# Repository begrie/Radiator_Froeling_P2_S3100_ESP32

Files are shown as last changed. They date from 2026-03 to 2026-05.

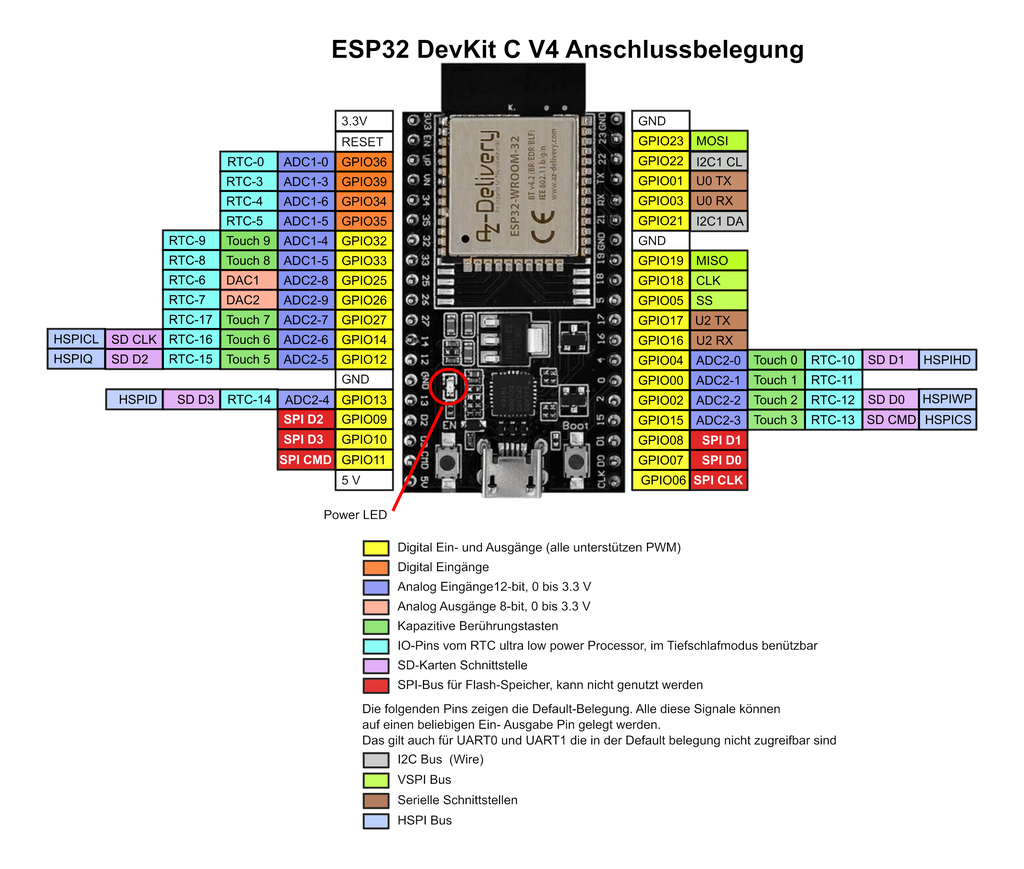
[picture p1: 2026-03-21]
Fotos/Pinout_ESP32DevkitCV4_AZDelivery.png

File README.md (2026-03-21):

# Überwachungstool für Fröling P2 / Lambdatronic S 3100 — ESP32-Adaptation

> **ESP32-Adaptation** von Bernd Griesbach (BeGrie) — basierend auf dem ursprünglichen Raspberry-Pi-Projekt von [Daniel Höpfl (dhoepfl/Radiator)](https://github.com/dhoepfl/Radiator).

## Anpassung für ESP32 (BeGrie, Sept./Okt. 2022)

Im Zuge der Energiekrise 2022 und einem Pelletspreisanstieg von 200 auf 800 Euro je Tonne habe ich mein seit langem geplantes und immer wieder beiseite geschobenes Projekt (Heizung seit 2006 im Betrieb) der Heizungsüberwachung wieder aktiviert um Optimierungspotentiale zu erschließen.

Bei der Recherche nach Lösungen bin ich unter anderem auf dieses Projekt von Daniel Höpfl gestoßen und war von Analyse des P2/S3100-Kommunikationsprotokolls und der professionellen Umsetzung in Sourcecode begeistert. Hiermit huldige ich dem Meister, von dem ich aus seinem Projekt einiges lernen durfte! Vielen Dank dafür!

Als ESP32 Nutzer habe ich mangels RasPi Erfahrungen und fehlender Erläuterungen im Projekt (sorry) doch etwas gebraucht, um den gesamten Ablauf auf dem RasPi mittels C++, Autoconf/Automake, Python und Shellskripten in Kombination mit mysql, rrd, Vu, mailserver etc. zu verstehen. Nun ist alles klar, aber ich brauche so viele Features davon nicht und bleibe doch lieber in den mir bekannten ESP32-Gefilden ...

Die ESP32 Lösung besteht nur noch aus dem C++ Sourcecode, bei dem ich im wesentlichen folgendes geändert bzw. ergänzt habe:

- main.cpp neu für ESP32 mit Platformio (bei mir in VSCode) -> Platform Espressif32 und Arduino framework 3.x

- Serieller Input (in serial.cpp) über Serial2 realisiert (hardwareseitig wie beim RasPi über RS232-Schnittstellenumsetzer → bei mir SparkFun Transceiver Breakout - MAX3232 https://www.sparkfun.com/products/11189)

- Output fast komplett neu (output.h/.cpp, network.h/.cpp, files.h/.cpp) → nun "autark" (ohne externe Skripte o.ä) auf
  - Console/Serial,
  - Flash/LittleFS (wg. geringem Speicherplatz nur zum Testen sinnvoll),
  - SD Card (hardwareseitig jeder 3,3V SD Reader an den ESP32 anschliessbar). Aktuell muss die SD Card entnommen und am PC eingelesen werden.
  - Buzzer (aktiv) und Quit-Button zur akustischen Fehlermeldung im Keller
  - WiFi ...
    _ ... inkl. Konfiguration über console/Serial per USB-Anschluss → beim Booten den Quit-Button drücken
    _ ... zum Versand von MQTT-Nachrichten (Konfiguration wie bei WiFi) \* ... mit Webserver zum Datenabgriff von der SD-Card

- Die Konfiguration bzgl. Filesystem, Output und weiterem Verhalten erfolgt ausschließlich über die #defines in config.h, was bei Änderungen natürlich eine Neucompilierung erfordert (ich weiss: nicht schön - aber der kürzeste Weg). Dies sollte aber durch die Nutzung von Platformio über die hier enthaltene platformio.ini problemlos möglich sein ...

- Schaltplan zur Konfiguration im Sourcecode:
  Schaltplan

- Fotos zur Umsetzung:
  Foto Platine oben
  Foto Platine unten
  Foto Heizung

Falls jemand die ESP32 Anpassung nutzt, bin ich für Rückmeldungen, Verbesserungen, Pull requests etc. offen ...

---

## Hintergrund: Originaltext von Daniel Höpfl ([dhoepfl/Radiator](https://github.com/dhoepfl/Radiator))

_Der folgende Abschnitt stammt aus dem ursprünglichen Raspberry-Pi-Projekt, auf dem diese ESP32-Adaptation basiert. Er enthält die detaillierte Protokollanalyse der Fröling P2 / Lambdatronic S 3100 Schnittstelle._

## Vorgeschichte

Fast alle Geräte in unserem Haushalt haben einen eingebauten Signalgeber, um uns zu informieren, wenn sie etwas von uns brauchen: Die Spülmaschine piept, wenn sie fertig ist, die Mikrowelle hat eine laute Klingel, die Waschmaschine ebenso, wie der Trockner. Das einzige Gerät, das keinen Ton von sich gibt, wenn es eine Störung erkennt, ist die Fröling P2 Pellet-Heizung im Keller. Es ist nicht so, dass die Heizung keine Störungen hätte oder diese nicht erkennt, nein: Wenn zum Beispiel ein zu großes Pellet den Saugschlauch blockiert, dann erkennt die Heizung das und ihre Status-LED blinkt nicht länger grün sondern rot. Dass wir das nicht bemerken, weil die Heizung hinter verschlossener Türe im Heizungskeller steht, daran hat bei Fröling wohl niemand gedacht.

Mein erster Ansatz war, eine kleine Überwachung zu bauen, die die Farbe der LED erkennt und darauf basierend einen Alarm auslöst. Ich bin Softwerker, kein Hardware-Profi. An der Erkennung der Farbe (zu kleinem Preis) bin ich gescheitert. Noch während ich daran gearbeitet habe, bin ich darauf gestoßen, dass die P2 bzw. die darin verbaute Lambdatronic S 3100 eine serielle Schnittstelle hat, über die sie praktisch voll bedienbar ist. Da ich zunächst eine Lösung wollte, für die ich mich nicht direkt mit der Heizung verbinden muss (Gewährleistung, Diskussionen mit dem Service, ...), habe ich diese Möglichkeit zunächst nicht weiter verfolgt.

Nachdem wir in den letzten Wochen mehrmals (Pellets-Lager wird leer) durch kaltes Wasser auf die Farbe der LED hingewiesen wurden, habe ich das Projekt wiederbelebt. Dieses Mal ist mir der Mitarbeiter der Wartungsfirma egal.

## Protokollanalyse

Das Protokoll der S 3100 ist halbwegs gut analysiert. Die beste Quelle ist [dieser Thread bei mikrocontroller.net](http://www.mikrocontroller.net/topic/319990 "Fröling Heizungssteuerung auslesen"). Auch wertvoll ist [dieser Eintrag auf rigert.com](http://rigert.com/wiki-wiki/index.php?title=Fr%C3%B6ling). Die einzige Quelle, die „M3“ erwähnt ist [das hier verlinkte Archiv eines Foren-City-Threads](http://www.labviewforum.de/Thread-Mit-RS232-Daten-lesen-und-schreiben?pid=159201#pid159201).

Die drei Quellen scheinen größtenteils voneinander abzuschreiben (Forencity ist dabei der älteste, gefolgt von mikrocontroller und dann rigert.com), allen gemein ist, dass meiner Ansicht nach keiner der dort Mitschreibenden das Protokoll verstanden hat. Da wird davon gesprochen, dass 32 Mal ein bestimmter Befehl gesendet werden müsste, um die Kommunikation am Laufen zu halten, oder dass man abwechselnd „M1“ und „M2“ abfragen müsste. Ich halte das für Blödsinn.

Nach meinen Analysen sieht das Protokoll wie folgt aus:

### Datenpakete

Das Protokoll basiert auf Datenpaketen mit folgender Struktur:

| Bytes | Beschreibung |
| ----- | --- |
| 2 | Befehl |
| 1 | Länge (n) |
| n | Daten |
| 2 | Prüfsumme |

Dabei gilt:

- Für eine Liste der bekannten Befehle siehe unten. Soweit ich sehen konnte, beginnen Befehle, die von der Heizung gesendet werden, mit „M“, Befehle, die vom Endgerät ausgehen, beginnen mit „R“. (Achtung: Das gilt nicht für Bestätigungen)
- Die Länge zählt nur die Datenbytes, Header und Prüfsumme bleiben unberücksichtigt.
- Die Prüfsumme ist eine einfache, vorzeichenlos berechnete, 16 Bit breite Summe über Befehl, Länge und Daten.

## Ablauf

Hier widerspreche ich den oben verlinkten Quellen: Meiner Meinung nach sieht das Protokoll vor, dass jedes Datenpaket mit einer Bestätigung quittiert wird. Dabei folgt das Bestätigungspaket folgendem Schema:

| Bytes | Beschreibung |
| ----- | --- |
| 2 | Befehl, der quittiert wird |
| 1 | Länge (immer 1) |
| 1 | 0x01 für Bestätigung (ACK), 0x00 für Fehler (NACK) |
| 2 | Prüfsumme |

Der Ablauf im Programm kann also wie folgt aussehen:

1.  Benutze einen Puffer für mindestens 260 Bytes (2 Bytes Befehl, 1 Byte Länge, max. 255 Bytes Daten, 2 Bytes Prüfsumme).
2.  5 Bytes von der seriellen Schnittstelle lesen (2 Byte Befehl, 1 Byte Länge, 2 Bytes Prüfsumme)
3.  Wenn Länge > 0: Entsprechend weitere Bytes lesen.
4.  Die Prüfsumme prüfen.
    - Ist sie ungültig: NACK senden, weiter bei 1.
    - Ist sie gültig: ACK senden, weiter bei 5.
5.  Bestätigungen behandeln:
    - Wurde der entsprechende Befehl gesendet und ist die Länge 1 und ist der Wert 0x01? Dann ist der Befehl quittiert, weiter bei 1.
    - Wurde der entspechende Befehl gesendet und ist die Länge 1 und ist der Wert 0x00? Dann Befehl erneut senden, weiter bei 1.
    - Wurde der entsprechende Befehl nicht gesendet oder ist die Länge nicht 1, dann weiter bei 6.
6.  Befehl behandeln.

## Bekannte Befehle

Hier die Beschreibung der Befehle, so wie ich sie zusammengetragen und verstanden habe. Das unterscheidet sich zum Beispiel bei „M1“ von dem, was man in den Foren findet, dort wird immer von einer festen Reihenfolge ausgegangen. Für eine bestimmte Heizung stimmt das vermutlich auch, solange nichts neues angeschlossen wird.

Alle Texte, die übertragen werden, sind übrigens in „Codepage 850“ kodiert. Ein (Mapping zu Unicode findet sich z.B. bei der Wikipedia)[https://de.wikipedia.org/wiki/Codepage_850].

### Login („Ra“)

| Bytes | Wert | Beschreibung |
| ----- | --- | --- |
| 2 | 0x52 0x61 | Login-Befehl |
| 1 | 0x03 | Länge 3 |
| 1 | 0x00 | unbekannt |
| 2 | 0x.. 0x.. | Benutzer-Kennung (-7: 0xff 0xf9 für Service, 1/0x00 0x01 für Kunde) |
| 2 | 0x.. 0x.. | Prüfsumme |

Die Heizung antwortet darauf mit einem ACK (siehe Ablauf) und sendet daraufhin die Befehlsblöcke MA, MB, MC, MD, ME, MF, MG, MK, ML, MM, MW, MS, MT und MU, jeweils beendet durch entsprechende MZ Befehle. Anschließend beginnt die Heizung regelmäßig M2 zu senden.

### Status („Rb“)

| Bytes | Wert | Beschreibung  |
| ----- | --- | --- |
| 2 | 0x52 0x62 | Status-Befehl |
| 1 | 0x03 | Länge 3 |
| 3 | 0x00 0x00 0x00 | unbekannt |
| 2 | 0x.. 0x.. | Prüfsumme |

Die Heizung antwortet darauf mit einem ACK (siehe Ablauf) und sendet ab sofort regelmäßig die Messwerte (M1).

### Parameter ändern („RI“)

Ändert einen der Werte der Heizung. Die verfügbaren Werte werden in „ME“ beschrieben.

| Bytes | Wert | Beschreibung |
| ----- | --- | --- |
| 2 | 0x52 0x49 | Befehl |
| 1 | 0x04 | Länge |
| 2 | 0x.. 0x.. | Parameter-ID |
| 2 | 0x.. 0x.. | Neuer Wert |
| 2 | 0x.. 0x.. | Prüfsumme |

Die Heizung antwortet darauf mit einem ACK/NACK (siehe Ablauf), anschließend kommt der neue Wert über „MI“.

### Messwerte („M1“)

Auch hier muss ich den Angaben aus den Foren widersprechen: Der Inhalt von M1 ist nicht fest vorgegeben, es hängt davon ab, was wie die Heizung installiert wurde. Welche Werte geliefert werden und wie diese zu interpretieren sind, kann man aus der „MA“- bzw. „MC“ Antworten ableiten, die man beim Login bekommt. Für meine Heizung sind das die folgenden Werte, für andere Heizungen können es andere Werte (oder Reihenfolgen) sein.

| Bytes | Wert | Beschreibung | Faktor | Einheit |
| ----- | --- | --- | :----: | :-----: |
| 2 | 0x4D 0x31 | Status-Befehl | | |
| 1 | 0x.. | Länge | | |
| 2 | 0x.. 0x.. | 1. Displayzeile | | |
| 2 | 0x.. 0x.. | 2. Displayzeile | | |
| 2 | 0x.. 0x.. | Zustand | 1 | -/- |
| 2 | 0x.. 0x.. | Rost | 1 | -/- |
| 2 | 0x.. 0x.. | Kessel-Temperatur | 2 | °C |
| 2 | 0x.. 0x.. | Abgas-Temperatur | 1 | °C |
| 2 | 0x.. 0x.. | Abgas Schwellwert | 1 | °C |
| 2 | 0x.. 0x.. | KesselStellGr | 1 | % |
| 2 | 0x.. 0x.. | Saugzug | 1 | % |
| 2 | 0x.. 0x.. | Zuluft-Gebläse | 1 | % |
| 2 | 0x.. 0x.. | Einschub | 1 | % |
| 2 | 0x.. 0x.. | Rest-O2 |  100 | % |
| 2 | 0x.. 0x.. | O2-Regler |  100 | % |
| 2 | 0x.. 0x.. | Füllstand |  207 | % |
| 2 | 0x.. 0x.. | Feuerraum-Temperatur | 2 | °C |
| 2 | 0x.. 0x.. | Puffer oben | 2 | °C |
| 2 | 0x.. 0x.. | Puffer unten | 2 | °C |
| 2 | 0x.. 0x.. | Puffer Pu | 1 | % |
| 2 | 0x.. 0x.. | Boiler | 2 | °C |
| 2 | 0x.. 0x.. | Außentemperatur | 2 | °C |
| 2 | 0x.. 0x.. | Vorlauf 1 Schwellwert  | 2 | °C |
| 2 | 0x.. 0x.. | Vorlauf 1 | 2 | °C |
| 2 | 0x.. 0x.. | Vorlauf 2 Schwellwert  | 2 | °C |
| 2 | 0x.. 0x.. | Vorlauf 2 | 2 | °C |
| 2 | 0x.. 0x.. | KTY6_H2 | 2 | °C |
| 2 | 0x.. 0x.. | KTY7_H2 | 2 | °C |
| 2 | 0x.. 0x.. | Brennerstarts | 1 | -/- |
| 2 | 0x.. 0x.. | Betriebsstunden | 1 | h |
| 2 | 0x.. 0x.. | Board-Temperatur | 1 | °C |
| 2 | 0x.. 0x.. | Kessel Soll-Temperatur | 2 | °C |
| 2 | 0x.. 0x.. | Prüfsumme | | |

### Zeit („M2“)

| Bytes | Wert | Beschreibung |
| ----- | --- | --- |
| 2 | 0x4D 0x32 | Befehl |
| 1 | 0x07 | Länge |
| 1 | 0x.. | Sekunden |
| 1 | 0x.. | Minuten |
| 1 | 0x.. | Stunden |
| 1 | 0x.. | Tag |
| 1 | 0x.. | Monat |
| 1 | 0x.. | Wochentag (1: Montag, ..., 7: Sonntag) |
| 1 | 0x.. | Jahr |
| 2 | 0x.. 0x.. | Prüfsumme |

Alle Werte sind BCD, d.h. die oberen 4 Bit beschreiben die Zehner-Stelle, die unteren 4 Bit die Einer-Stelle.

### Fehlermeldung („M3“)

Wird gesendet, wenn ein Fehler auftritt. Vermutlich die interessanteste Meldung überhaupt, jedenfalls für meinen Anwendungszweck!

| Bytes | Wert | Beschreibung |
| ----- | --- | --- |
| 2 | 0x4D 0x33 | Befehl |
| 1 | 0x0a | Länge |
| 1 | 0x.. | Fehlertext-ID |
| 1 | 0x.. | Unbekannt |
| 1 | 0x.. | Unbekannt |
| 1 | 0x.. | Sekunden |
| 1 | 0x.. | Minuten |
| 1 | 0x.. | Stunden |
| 1 | 0x.. | Tag |
| 1 | 0x.. | Monat |
| 1 | 0x.. | Wochentag (1: Montag, ..., 7: Sonntag) |
| 1 | 0x.. | Jahr |
| 2 | 0x.. 0x.. | Prüfsumme |

Der Inhalt entspricht dem von „MU“, die Fehlertext-ID ist analog denen in „MT“.

### Bezeichnung der Parameter in „M1“ („MA“)

Diese Nachrichten müssen ausgewertet werden, um den Inhalt von „M1“ auswerten zu können. Die Werte in „M1“ sind jeweils 2 Byte lang und werden in genau der Reihenfolge gesendet, in der auch die „MA“ Nachrichten gesendet wurden.

| Bytes | Wert | Beschreibung |
| ----- | --- | --- |
| 2 | 0x4D 0x41 | Befehl |
| 1 | 0x.. | Länge |
| 1 | 0x.. | 'S': String, 'I': Messwerte |
| 2 | 0x.. 0x.. | 'S': Typ in „MB“, 'I': Index in „MC“ |
| 2 | 0x.. 0x.. | Unbekannt |
| n | ... | Parameterbezeichnung |
| 2 | 0x.. 0x.. | Prüfsumme |

### Displaytexte („MB“)

Enthält die Texte, die in „MA“ referenziert werden. Bisher bekannt sind die beiden Typen 0 und 1, welche in der ersten bzw. zweiten Displayzeile angezeigt werden.

| Bytes | Wert | Beschreibung |
| ----- | --- | --- |
| 2 | 0x4D 0x42 | Befehl |
| 1 | 0x.. | Länge |
| 2 | 0x.. 0x.. | Typ (0: obere Displayzeile, 1: untere Displayzeile) |
| 2 | 0x.. 0x.. | Index der Nachricht |
| n | Text | Nachrichtentext |
| 2 | 0x.. 0x.. | Prüfsumme |

### Datenformat der Werte in „M1“ („MC“)

Beschreibt, wie die Daten in „M1“ formatiert werden müssen. Da es bei mir deutlich mehr „MC“-Datensätze, als für „MA“ gibt, gehe ich davon aus, dass die übrigen Einträge anderweitig referenziert werden. Wo habe ich noch nicht herausgefunden.

| Bytes | Wert | Beschreibung |
| ----- | --- | --- |
| 2 | 0x4D 0x43 | Befehl |
| 1 | 0x08 | Länge |
| 2 | 0x.. 0x.. | Index |
| 1 | 0x.. | Einheit (Codepage 850 beachten!) |
| 1 | 0x.. | Anzahl der Nachkommastellen |
| 2 | 0x.. 0x.. | Anzuwendender Teiler |
| 2 | 0x.. 0x.. | Unbekannt (Häufig gleich Teiler, aber nicht immer) |
| 2 | 0x.. 0x.. | Prüfsumme |

### Einstellungsmenü („MD“)

Aus den Foren übernommen, Zweck unbekannt.

| Bytes | Wert | Beschreibung |
| ----- | --- | --- |
| 2 | 0x4D 0x44 | Befehl |
| 1 | 0x.. | Länge |
| 1 | 0x.. | Unbekannt |
| 2 | 0x.. 0x.. | Unbekannt |
| 2 | 0x.. 0x.. | Unbekannt |
| 2 | 0x.. 0x.. | Unbekannt |
| n | | Text |
| 2 | 0x.. 0x.. | Prüfsumme |

### Parameterbeschreibung („ME“)

Aus den Foren übernommen, Zweck unbekannt. Hängt vermutlich mit „MD“ zusammen.

| Bytes | Wert | Beschreibung |
| ----- | --- | --- |
| 2 | 0x4D 0x45 | Befehl |
| 1 | 0x.. | Länge |
| 2 | 0x.. 0x.. | Parameter-ID |
| 1 | 0x.. | Einheit |
| 1 | 0x.. | Nachkommastellen |
| 2 | 0x.. 0x.. | Faktor |
| 2 | 0x.. 0x.. | Minimalwert |
| 2 | 0x.. 0x.. | Maximalwert |
| 2 | 0x.. 0x.. | Standardwert |
| 5 | ... | Unbekannt |
| 2 | 0x.. 0x.. | Prüfsumme |

### Texte Betriebsmodus („MF“)

Enthält je einen Eintrag für die Betriebsmodi („Sommerbetrieb“, „Winterbetrieb“, …). Wo die Einträge referenziert werden ist nicht mir noch nicht klar.

| Bytes | Wert | Beschreibung |
| ----- | --- | --- |
| 2 | 0x4D 0x46 | Befehl |
| 1 | 0x.. | Länge |
| 2 | 0x.. 0x.. | Text-ID |
| n | ... | Text |
| 2 | 0x.. 0x.. | Prüfsumme |

### Wochenprogramm Heizkreise („MG“)

Noch nicht weiter analysiert.

| Bytes | Wert | Beschreibung |
| ----- | --- | --- |
| 2 | 0x4D 0x47 | Befehl |
| 1 | 0x12 | Länge |
| 2 | 0x.. 0x.. | Heizkreis-Nummer |
| 1 | 0x.. | Unbekannt |
| 7 | ... | Programmnummer für jeden Tag (Sonntag - Samstag), siehe MK |
| 1 | 0x.. | Unbekannt |
| 7 | ... | Programmnummer für jeden Tag (Sonntag - Samstag), siehe MK |
| 2 | 0x.. 0x.. | Prüfsumme |

### Parameteränderung („MI“)

Wird gesendet, wenn einer der Heizungsparameter geändert wurde (z.B. durch Befehl „RI“).

| Bytes | Wert | Beschreibung |
| ----- | --- | --- |
| 2 | 0x4D 0x49 | Befehl |
| 1 | 0x04 | Länge |
| 2 | 0x.. 0x.. | Parameter-ID |
| 2 | 0x.. 0x.. | Neuer Wert |
| 2 | 0x.. 0x.. | Prüfsumme |

### Tagesprogramm („MK“)

Noch nicht weiter analysiert.

| Bytes | Wert | Beschreibung |
| ----- | --- | --- |
| 2 | 0x4D 0x4B | Befehl |
| 1 | 0x06 | Länge |
| 2 | 0x.. 0x.. | Programmnummer |
| 2 | 0x.. 0x.. | Unbekannt |
| 2 | 0x.. 0x.. | Unbekannt |
| 2 | 0x.. 0x.. | Prüfsumme |

### Produktnamen („ML“)

Enthält diverse Namen von Heizungen. Wo diese Texte referenziert werden ist mir noch nicht klar.

| Bytes | Wert | Beschreibung |
| ----- | --- | --- |
| 2 | 0x4D 0x4C | Befehl |
| 1 | 0x.. | Länge |
| 10 | ... | Unbekannt |
| n | ... | Name |
| 2 | 0x.. 0x.. | Prüfsumme |

### Features („MM“)

Enthält diverse Meldungen, welche Optionen eingebaut sind. Wo diese Texte referenziert werden ist mir noch nicht klar.

| Bytes | Wert | Beschreibung |
| ----- | --- | --- |
| 2 | 0x4D 0x4C | Befehl |
| 1 | 0x.. | Länge |
| 4 | ... | Unbekannt |
| n | ... | Meldung |
| 2 | 0x.. 0x.. | Prüfsumme |

### Weitere texte („MW“)

Wo diese Texte referenziert werden ist mir noch nicht klar.

| Bytes | Wert | Beschreibung |
| ----- | --- | --- |
| 2 | 0x4D 0x4C | Befehl |
| 1 | 0x.. | Länge |
| 2 | ... | Unbekannt |
| n | ... | Text |
| 2 | 0x.. 0x.. | Prüfsumme |

### Fehlerprotokoll-Texte („MT“)

Enthält Beschreibungen für mögliche Fehler im Fehlerprotokoll „MU“.

| Bytes | Wert | Beschreibung |
| ----- | --- | --- |
| 2 | 0x4D 0x54 | Befehl |
| 1 | 0x.. | Länge |
| 1 | 0x.. | Text-ID |
| n | ... | Text |
| 2 | 0x.. 0x.. | Prüfsumme |

### Fehlerprotokoll („MU“)

| Bytes | Wert | Beschreibung  |
| ----- | --- | --- |
| 2 | 0x4D 0x55 | Befehl |
| 1 | 0x.. | Länge |
| 1 | 0x.. | Fehlertext-ID |
| 1 | 0x.. | Unbekannt |
| 1 | 0x.. | Unbekannt |
| 1 | 0x.. | Sekunden |
| 1 | 0x.. | Minuten |
| 1 | 0x.. | Stunden |
| 1 | 0x.. | Tag |
| 1 | 0x.. | Monat |
| 1 | 0x.. | Unbekannt |
| 1 | 0x.. | Jahr |
| 2 | 0x.. 0x.. | Prüfsumme |

### Fehlerprotokoll („MV“)

Dass es „MV“ gibt weiß ich, weil ich ein entsprechendes „MZ“ gesehen habe. Allerdings habe ich noch kein „MV“ gesehen.

### Blockende („MZ“)

Beendet die Übertragung eines der obigen Daten-Blöcke.

| Bytes | Wert | Beschreibung |
| ----- | --- | --- |
| 2 | 0x4D 0x55 | Befehl |
| 1 | 0x01 | Länge |
| 1 | 0x.. | Beendeter Block |
| 2 | 0x.. 0x.. | Prüfsumme |

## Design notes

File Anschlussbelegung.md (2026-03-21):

# Froeling P2 ESP32

## Anschlussbelegung (GPIO)

Stand: aus src/config.h und aktueller Code-Nutzung

## Seriell

- USB-Konsole (Setup/Logs): UART0 ueber Board-USB, Monitor 115200 Baud
- Hinweis: RS232-TTL Wandler noetig (z. B. MAX3232):
  - Heizung P2/S3100 RX: GPIO16 (ESP-Eingang), Serial2 mit 9600 8N1
  - Heizung P2/S3100 TX: GPIO17 (ESP-Ausgang), Serial2 mit 9600 8N1

## Speicher

- SD Card CS: GPIO5 (Ausgang)
- SD SPI SCK: GPIO18
- SD SPI MISO: GPIO19
- SD SPI MOSI: GPIO23
- SD SPI Speed: 4 MHz
- Hinweis: entspricht der ueblichen VSPI-Belegung beim ESP32 DevKit

## Bedienung / Signale

- Buzzer (aktiv): GPIO27, digital HIGH/LOW
- Quit-/Setup-Button: GPIO13, INPUT_PULLUP, aktiv LOW
- Button-Funktion beim Boot: WLAN/MQTT-Setup starten
- Button-Funktion im Betrieb: Buzzer quittieren

## Externe Sensoren / Aktoren

- DHT11 Temp/Feuchte: GPIO21
  Aktiv nur wenn USE_EXTERNAL_SENSORS=true und WITH_DHT_SENSOR=true

- Ventilator-Relais: GPIO22
  Aktiv nur wenn USE_EXTERNAL_SENSORS=true und WITH_VENTILATOR=true

- Servo Luftklappe: GPIO25
  Aktiv nur wenn USE_EXTERNAL_SENSORS=true und WITH_AIR_INPUT_FLAP=true

- Leckwasser-Sensor: GPIO39 (Eingang)
  Aktiv wenn USE_EXTERNAL_SENSORS=true
  Hinweis: GPIO39 ohne internen Pullup, Auswertung per Interrupt (CHANGE)

- AC-Stromsensor: GPIO33 (Analog-Eingang)
  Aktiv wenn USE_EXTERNAL_SENSORS=true

## Aktueller Feature-Status

- USE_WIFI=true
- START_WEBSERVER=false
- OUTPUT_TO_MQTT=true
- OUTPUT_TO_FILE=true
- USE_EXTERNAL_SENSORS=true
- WITH_DHT_SENSOR=false
- WITH_VENTILATOR=false
- WITH_AIR_INPUT_FLAP=false

## Kurzcheck vor Verdrahtung

1. Heizungsschnittstelle auf GPIO16/17 und 9600 8N1 pruefen.
2. Buzzer auf GPIO27, Button auf GPIO13 gegen GND (aktiv LOW).
3. SD-CS auf GPIO5 pruefen.
4. SD-SPI-Leitungen auf GPIO18/19/23 pruefen (SCK/MISO/MOSI).
5. Externe Sensorik nur verdrahten, wenn der jeweilige Feature-Schalter aktiv ist.

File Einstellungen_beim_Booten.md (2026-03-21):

# Froeling P2 ESP32

## Systemeinstellungen beim Booten ändern

### Voraussetzungen vor dem Boot

- Serielle-Konsole oeffnen (PlatformIO Monitor)
- Monitor-Parameter: 115200 Baud, Echo EIN
- Zeilenende fuer Eingaben: CR oder CRLF

---

### Boot ohne gedrueckten Button (Normalfall)

- ESP nutzt gespeicherte WLAN-Daten aus NVS (persistent)
- WLAN-Verbindung startet im Hintergrund
- MQTT nutzt gespeicherte Broker/User/Pass-Daten
- Kein Konsolen-Dialog

Hinweis:

- Wenn keine gueltigen WLAN-Daten gespeichert sind, kann WLAN-Start fehlschlagen.

---

### Boot MIT gedruecktem gelben Quit-Button (Konfig-Modus)

Button beim Einschalten gedrueckt halten.

Ablauf in der Konsole:

1. WLAN-Scan wird gestartet, gefundene SSIDs werden nummeriert angezeigt.
2. Auswahl eingeben:
   - Zahl 1..N: dieses WLAN verwenden
   - 0: WLAN komplett AUS (gespeicherte AP-Daten loeschen)
   - -1: WLAN unveraendert lassen, nur MQTT-Einstellungen aendern
3. Bei Auswahl 1..N: WLAN-Passwort eingeben.
4. Danach MQTT-Dialog:
   - Broker: ENTER = behalten, 0 = loeschen/deaktivieren, sonst neuer Wert
   - User: ENTER = behalten, 0 = loeschen, sonst neuer Wert
   - Pass: ENTER = behalten, 0 = loeschen, sonst neuer Wert
5. Werte werden persistent im NVS gespeichert.

---

### Schnelle Bedienlogik am Geraet

- Nur normal starten: Button NICHT druecken
- WLAN/MQTT neu einstellen: Button beim Boot druecken
- MQTT abschalten: Im MQTT-Broker-Feld "0" eingeben
- WLAN abschalten: Bei Netzwerkauswahl "0" eingeben

---

### Merksatz

Button beim Boot = Setup-Menue.
Kein Button = gespeicherte Konfiguration verwenden.

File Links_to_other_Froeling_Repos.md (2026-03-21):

Links zu anderen Repositories zu Froeling-Pelletsheizungen

Deamon which fetch sensor data of the 'Lambdatronic s3200' and store to a MySQL database:
https://github.com/horchi/linux-p4d

Fröling P3100 Wifi ESP8266 Wifi Communication
https://github.com/mkliche/froeling-com

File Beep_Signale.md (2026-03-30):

# Froeling P2 ESP32

## Beep-Signale

## Prioritaetsreihenfolge (hoechste zuerst)

| Prio | Signal | Bedeutung |
| ---- | --- | --- |
| 6 | Dauerton | Leckwasser |
| 5 | Stotter-Alarm | Grenzwert ueberschritten |
| 4 | Intervall-Piepen | Heizungs-Fehlermeldung |
| 3 | Morse-S (···) | Heizung nicht verbunden |
| 2 | Rattern (zyklisch) | SD/Dateisystem-Problem (ESP) |
| 1 | 2 langsame Beeps | WiFi unterbrochen (ESP) |

---

## Quit-Taste (gelbe Taste an ESP-Box)

- Stoppt den aktiven Buzzer sofort.
- Bei **Heizungsalarmen (Prio 3-6):** Buzzer pausiert fuer **1 Minute**. Danach kommt der Alarm erneut, solange die Ursache noch besteht.
- Alarme der Heizungssteuerung (Prio 4) muessen zudem **ZUERST an der Heizung selbst** quittiert werden.
- WLAN-Ausfall hat einen eigenen zyklischen Buzzer (Prio 1) (Quit-Taste ohne Wirkung)

---

> **Unterscheidung:** Die Signale sind in zwei Kategorien eingeteilt:
>
> - **HEIZUNG KRITISCH** (Prioritaet 3-6): Direkte Heizungsanlage betroffen -> sofort handeln
> - **ESP-UEBERWACHUNG** (Prioritaet 1-2): Ueberwachungssystem selbst meldet ein Problem

---

## HEIZUNG KRITISCH

### 6) Dauerton (ohne Pause) - PRIO 6

**Bedeutung:** LECKWASSER erkannt
**Aktion:** Sofort auf Wasserleck pruefen, Bereich sichern, Ursache beheben.

---

### 5) Stotter-Alarm in Bloecken - PRIO 5

**Muster:** 4x kurz (120 ms EIN / 120 ms AUS), dann 1 s Pause, Wiederholung
**Bedeutung:** Grenzwert ueberschritten (z. B. Kesseltemperatur > 90 C)
**Aktion:** Anlage und Messwerte sofort kontrollieren.

---

### 4) Langsames Intervall-Piepen - PRIO 4

**Muster:** ca. 0,7 s EIN / 0,7 s AUS
**Bedeutung:** Heizungs-Fehlermeldung (Error-Alarm der Heizungssteuerung)
**Aktionen:**

1. Fehlertext auf Heizungsdisplay pruefen
2. Ursache beheben und Stoerung **an der Heizungssteuerung** quittieren (Enter-Taste)
3. Danach Buzzer an der ESP-Box mit der **gelben Quit-Taste** stoppen

---

### 3) Morse-S (3 kurze Beeps, Pause) - PRIO 3

**Muster:** · · · (3x 150 ms), dann 4 s Pause, Wiederholung
**Bedeutung:** Heizung sendet seit ca. 10 Minuten keine Daten mehr
**Aktion:** Serielle Verbindung Heizung <-> ESP-Box pruefen (Kabel, Stecker), Heizung manuell auf Fehler kontrollieren.

---

## ESP-UEBERWACHUNG

### 2) Rattern (3 Sekunden, alle 5 Minuten) - PRIO 2

**Muster:** sehr schnelle Pulse (~50 ms), klingt wie Rattern, ca. 3 Sekunden lang, dann 5 Minuten Pause, dann Wiederholung
**Bedeutung:** Dateisystem-/SD-Karten-Problem (ESP-Ueberwachung betroffen, nicht Heizung selbst)
**Aktion:** SD-Karte und Dateisystem pruefen; bei Wiederholung ESP-Geraet neu starten durch Reset-Button.

---

### 1) 2 langsame Beeps (alle 60 Sekunden) - PRIO 1

**Muster:** 2 x 600 ms EIN + 300 ms Pause, dann 60 Sekunden Pause, Wiederholung
**Bedeutung:** WiFi-Verbindung unterbrochen (ESP laeuft weiter, kein MQTT moeglich)
**Aktion:** Router/WLAN pruefen. Die Heizungsueberwachung laeuft lokal weiter und protokolliert auf SD-Karte.

---

## Statusinfo (kein Alarm)

### 5 schnelle Beeps (kurz)

**Bedeutung:** WLAN-Verbindung hergestellt
**Aktion:** Keine
_(Hinweis: Die Beeps entfallen, wenn gleichzeitig ein Heizungsalarm aktiv ist.)_

### 3 mittlere Beeps (500 ms, einmalig)

**Bedeutung:** ESP32 wird neu gestartet (Exception/Systemfehler)
**Aktion:** MQTT-Syslog pruefen. Wenn Neustarts sich wiederholen -> Geraet physisch inspizieren.

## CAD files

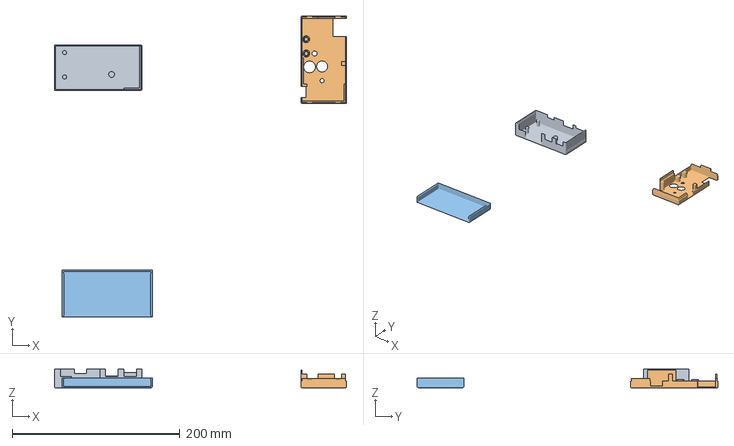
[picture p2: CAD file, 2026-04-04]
FroelingESP32Housing.3mf
348.5 x 359.0 x 22.2 mm
Unterteil
Zusammenbau x 2

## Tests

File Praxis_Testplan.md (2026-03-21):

# Froeling P2 ESP32

## Praxis-Testplan (Kurzcheck vor Ort)

1. **WLAN-Ausfall testen (Prio 1):** WLAN am Router kurz deaktivieren oder ESP aus dem WLAN nehmen -> nach kurzer Zeit muss das Prio-1-Muster zyklisch kommen; nach Wiederverbindung muessen die Alarme verschwinden.
2. **Dateisystem-Hinweis pruefen (Prio 2):** Nur kontrolliert im Servicefall ausloesen (z. B. mit bekannter Testprozedur) -> Rattern muss zyklisch wiederkehren.
3. **Heizung still pruefen (Prio 3):** Serielle Verbindung testweise trennen (Servicefenster) -> nach Timeout muss Morse-S aktiv werden; nach Wiederverbindung wieder aus.
4. **Heizungsfehler pruefen (Prio 4):** Bei realer Heizungsstoerung oder Service-Simulation pruefen -> Intervall-Piepen aktiv; erst an Heizung quittieren, dann gelbe Quit-Taste an ESP testen.
5. **Grenzwertalarm pruefen (Prio 5):** Mit sicherem Testwert/Simulation ueber Schwellwert gehen -> Stotter-Alarm muss sofort aktiv werden und bei Normalwert wieder enden.
6. **Leckwasser pruefen (Prio 6):** Leckwassersensor gemaess Wartungsanleitung ausloesen -> Dauerton muss Prioritaet haben und andere Signale ueberlagern.
7. **Quit-Taste pruefen:** Bei aktivem Prio-3 bis Prio-6 Alarm gelbe Taste druecken -> sofort stumm, danach erneutes Signal nach ca. 1 Minute, falls Ursache weiter aktiv ist.
8. **Restart-Signal pruefen:** Kontrollierten Neustart ausloesen -> einmalig 3 mittlere Beeps; bei wiederholten Neustarts Syslog/MQTT und Stromversorgung pruefen.

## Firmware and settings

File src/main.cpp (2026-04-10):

/******************************************************************************
 * Name:		main.cpp
 * @brief   Überwachungstool für Fröling P2 / Lambdatronic S 3100
 *          -> hier: für ESP32
 *          -> Output auf console, flash-filesystem oder SD-card oder/und MQTT
 *          -> rudimentärer Zugriff per WiFi Async Server
 *          -> IDE: platformio
 * Created:	01.09.2022 (ESP32-adaption)
 * Author:	Original (for Raspberry Pi): Daniel Höpfl
 *          -> https://github.com/dhoepfl/Radiator
 *          Adaption to ESP32: Bernd Griesbach
 *          -> https://github.com/begrie/Radiator_Froeling_S3100_Hoepfl/tree/ESP32
 ******************************************************************************/

/***********************
 *      INCLUDES
 ***********************/
#include "config.h"
#include "debug.h"
#include "device.h"
#include "surveillance.h"
#include "output.h"
#include "files.h"
#include "externalsensors.h"
#include "alarm.h"

/***********************
 *      DEFINES
 ***********************/
// see config.h

/***********************
 *      MACROS
 ***********************/
// see config.h

/***********************
 * FORWARD DECLARATIONS
 ***********************/

/***********************
 * GLOBAL DEFINITIONS
 ***********************/
radiator::NetworkHandler netHandler;
radiator::OutputHandler *ptrOutHandler;

/*********************************************************************
 * @brief 	Setup to start everything
 * @param 	void
 * @return 	void
 *********************************************************************/
void setup()
{
    // int *p = nullptr;
    // *p = 42; // absichtlicher Crash

    Serial.begin(115200);
    delay(1000); // give serial monitor time to connect
    Serial.println("Start setup...");

    bool outputToConsole = OUTPUT_TO_CONSOLE;
    bool outputToMQTT = OUTPUT_TO_MQTT && USE_WIFI; // is turned off without WiFi

    debug_level = D_DEBUG_LEVEL; // var debug_level is globally defined in debug.cpp

    // initialisation of the filesystem at first to minimize heap fragmentation
    std::string pathnameToDataDirectory =
        radiator::FilesystemHandler::initFilesystem(DATA_DIRECTORY); // DATA_DIRECTORY is completed with mountpoint of the filesystem
                                                                     // (/sd/dataDirectory or /littlefs/..., /spiffs/...)

    if (pathnameToDataDirectory.empty())
    {
        std::cout << getMillisAndTime() << "ERROR MOUNTING FILESYSTEM !!! -> Instead: data output to console (std::cout)" << std::endl;
        outputToConsole = true;
    }
    else // filesystem successfull mounted
    {
        // FS_Filehelper::listDir("/", 255, false, FILESYSTEM_TO_USE);

#if REDIRECT_STD_ERR_TO_SYSLOG_FILE
        if (!pathnameToDataDirectory.empty())
            radiator::FilesystemHandler::initRedirectStdErrToSyslogFile();
#endif
    }

    if (!OUTPUT_TO_FILE)
        pathnameToDataDirectory = ""; // empty pathname indicates "no file output" for constuctor of OutputHandler

    if (USE_WIFI)
        outputToMQTT = netHandler.init(outputToMQTT, START_WEBSERVER); // on init-failure -> turn off MQTT

    radiator::AlarmManager::init(); // must be called before any alarm can be raised

#if USE_EXTERNAL_SENSORS
    radiator::ExternalSensors::initExternalSensors();
#endif

    ptrOutHandler = new radiator::OutputHandler(pathnameToDataDirectory, // with empty pathnameToDataDirectory -> no output to file
                                                outputToConsole,
                                                outputToMQTT);

    // ptrOutHandler->setSystemTimeFromRadiatorData(2024, 9, 8, 7, 55, 44);

    RADIATOR_LOG_INFO("\n" << getMillisAndTime()
                           << "***************************************** END STARTUP OF ESP32 *****************************************" << std::endl;)
}

/*********************************************************************
 * @brief 	Loop function
 * @param 	void
 * @return 	void
 *********************************************************************/
void loop()
{
    std::string message;
    message.reserve(800); // an attempt to avoid heap fragmentation
    const char *loopStage = "init";

    // Track how long the boiler has been unreachable.
    // BOILER_SILENT_TIMEOUT_S is defined in config.h.
    static ulong boilerLostSinceMs = 0;
    static bool boilerWasConnected = false;

    try
    {
        loopStage = "build-start-message";
        message = getMillisAndTime() + "##### Start connecting to Froeling P2/S3100 ##### \n";
        loopStage = "publish-start-message";
        netHandler.publishToMQTT(message, MQTT_SUBTOPIC_SYSLOG);
        RADIATOR_LOG_WARN(message << std::endl;)
        if (REDIRECT_STD_ERR_TO_SYSLOG_FILE) // for better user info also to console
            std::cout << message;

        // Start BOILER_SILENT watchdog: if surveillance.main_loop() returns without
        // ever having received data, we count waiting time.
        if (!boilerWasConnected && boilerLostSinceMs == 0)
            boilerLostSinceMs = millis();

        loopStage = "surveillance-main-loop";
        radiator::Surveillance surveillance(S_SERIAL_TO_RADIATOR, T_TIMEOUT_BETWEEN_TRANSFERS_MS, *ptrOutHandler);
        surveillance.main_loop();

        // Only treat boiler as connected if at least one valid packet was received.
        if (surveillance.hadValidPacket())
        {
            loopStage = "connected-message";
            radiator::AlarmManager::clear(radiator::AlarmManager::Level::BOILER_SILENT);

            const std::string connectedMsg = getMillisAndTime() + " ##### CONNECTED to Froeling P2/S3100 #####";
            netHandler.publishToMQTT(connectedMsg, MQTT_SUBTOPIC_SYSLOG);
            RADIATOR_LOG_WARN(connectedMsg << std::endl;)
            if (REDIRECT_STD_ERR_TO_SYSLOG_FILE)
                std::cout << connectedMsg << std::endl;

            boilerWasConnected = true;
            boilerLostSinceMs = 0;
        }
        // Connection dropped after main_loop returned. Re-arm BOILER_SILENT timing
        // so later disconnects are also detected after previous successful sessions.
        else if (boilerWasConnected)
        {
            boilerWasConnected = false;
            boilerLostSinceMs = millis();
        }
        else if (boilerLostSinceMs == 0)
        {
            boilerLostSinceMs = millis();
        }

        loopStage = "build-retry-message";
        message = getMillisAndTime() + "##### Cannot establish connection to Froeling P2/S3100 -> retry in 10s ##### \n";
        loopStage = "publish-retry-message";
        netHandler.publishToMQTT(message, MQTT_SUBTOPIC_SYSLOG);
        RADIATOR_LOG_WARN(message << std::endl;)
        if (REDIRECT_STD_ERR_TO_SYSLOG_FILE) // for better user info also to console
            std::cout << message;

        // Check if boiler has been silent long enough to raise BOILER_SILENT alarm.
        if (boilerLostSinceMs > 0 &&
            (millis() - boilerLostSinceMs) >= (BOILER_SILENT_TIMEOUT_S * 1000UL))
        {
            radiator::AlarmManager::raise(radiator::AlarmManager::Level::BOILER_SILENT,
                                          "Heizung sendet keine Daten - bitte pruefen");
        }

        loopStage = "delay-before-next-loop";
        delay(10000);
    }
    catch (const std::bad_alloc &)
    {
        // Keep this path allocation-free as far as possible.
        Serial.print("FATAL: std::bad_alloc in loop stage '");
        Serial.print(loopStage);
        Serial.println("' -> restarting ESP32 in 10s");

        pinMode(BUZZER_PIN, OUTPUT);
        for (int i = 0; i < radiator::alarmcfg::RESTART_STATUS_BEEP_COUNT; i++)
        {
            digitalWrite(BUZZER_PIN, HIGH);
            delay(radiator::alarmcfg::RESTART_STATUS_ON_MS);
            digitalWrite(BUZZER_PIN, LOW);
            delay(radiator::alarmcfg::RESTART_STATUS_OFF_MS);
        }

        delay(10000);
        esp_restart();
    }
    catch (const char *error)
    {
        const std::string errorText = (error ? error : "<null>");
        message = getMillisAndTime() +
                  " ms: !!!!!!!!!!!!!!!!!!!!!!!!!!!!!!!!!!!!!!!!!!!!!!!!!!!!!!!!!!!!!!!!!!!\n"
                  "!!!!! error= " +
                  errorText +
                  "!!!!! Failed to open serial device or filesystem -> restarting ESP32 in 10s !!!!!\n"
                  "!!!!!!!!!!!!!!!!!!!!!!!!!!!!!!!!!!!!!!!!!!!!!!!!!!!!!!!!!!!!!!!!!!!!!!!!!!!!!!!!!";
        netHandler.publishToMQTT(message, MQTT_SUBTOPIC_SYSLOG);
        LOG_fatal << message << std::endl;
        Serial.println(message.c_str());

        // 3 langsame Beeps = ESP-Neustart (direkt auf GPIO; vor Restart sicher nutzbar)
        pinMode(BUZZER_PIN, OUTPUT);
        for (int i = 0; i < radiator::alarmcfg::RESTART_STATUS_BEEP_COUNT; i++)
        {
            digitalWrite(BUZZER_PIN, HIGH);
            delay(radiator::alarmcfg::RESTART_STATUS_ON_MS);
            digitalWrite(BUZZER_PIN, LOW);
            delay(radiator::alarmcfg::RESTART_STATUS_OFF_MS);
        }

        delay(10000);
        esp_restart();
    }
    catch (const std::exception &e)
    {
        message = getMillisAndTime() + " ms: EXCEPTION in loop(): " + e.what() +
                  " -> restarting ESP32 in 10s";
        netHandler.publishToMQTT(message, MQTT_SUBTOPIC_SYSLOG);
        LOG_fatal << message << std::endl;
        Serial.println(message.c_str());

        // 3 langsame Beeps = ESP-Neustart
        pinMode(BUZZER_PIN, OUTPUT);
        for (int i = 0; i < radiator::alarmcfg::RESTART_STATUS_BEEP_COUNT; i++)
        {
            digitalWrite(BUZZER_PIN, HIGH);
            delay(radiator::alarmcfg::RESTART_STATUS_ON_MS);
            digitalWrite(BUZZER_PIN, LOW);
            delay(radiator::alarmcfg::RESTART_STATUS_OFF_MS);
        }

        delay(10000);
        esp_restart();
    }
    catch (...)
    {
        message = getMillisAndTime() + " ms: UNKNOWN EXCEPTION in loop() -> restarting ESP32 in 10s";
        netHandler.publishToMQTT(message, MQTT_SUBTOPIC_SYSLOG);
        LOG_fatal << message << std::endl;
        Serial.println(message.c_str());

        // 3 langsame Beeps = ESP-Neustart
        pinMode(BUZZER_PIN, OUTPUT);
        for (int i = 0; i < radiator::alarmcfg::RESTART_STATUS_BEEP_COUNT; i++)
        {
            digitalWrite(BUZZER_PIN, HIGH);
            delay(radiator::alarmcfg::RESTART_STATUS_ON_MS);
            digitalWrite(BUZZER_PIN, LOW);
            delay(radiator::alarmcfg::RESTART_STATUS_OFF_MS);
        }

        delay(10000);
        esp_restart();
    }
}

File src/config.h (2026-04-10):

/******************************************************************************
 * Name:		config.h
 * @brief   Konfiguration für Überwachungstool für Fröling P2 / Lambdatronic S 3100
 *          -> hier: für ESP32
 *          -> Output auf console, flash-filesystem oder SD-card oder/und MQTT
 *          -> rudimentärer Zugriff per WiFi Async Server
 *          -> IDE: platformio
 * Created:	01.09.2022 (ESP32-adaption)
 * Author:	Original (for Raspberry Pi): Daniel Höpfl
 *          -> https://github.com/dhoepfl/Radiator
 *          Adaption to ESP32: Bernd Griesbach
 *          -> https://github.com/begrie/Radiator_Froeling_P2_S3100_ESP32
 ******************************************************************************/
#ifndef __DH_CONFIG_H__
#define __DH_CONFIG_H__

/*********************
 *      INCLUDES
 *********************/
#include <Arduino.h>
#include <SD.h>
// #include <LittleFS.h>
// #include <SPIFFS.h>
//  #include <chrono>

namespace radiator
{

/*********************
 *      DEFINES
 *********************/
#define D_DEBUG_LEVEL 2 // 0 - No logging
                        // 1 - Errors
                        // 2 - Warnings
                        // 3 - Infos
                        // 4 - Debug
                        // 5 - Trace

#define REDIRECT_STD_ERR_TO_SYSLOG_FILE false    // debug output to file INSTEAD to console/Serial
                                                 // -> do it only with D_DEBUG_LEVEL 0, 1 or 2
#define SYSLOG_DIR "/syslog"                     // directory for syslog files
#define SYSLOG_PATHNAME SYSLOG_DIR "/syslog.log" // name with path (only one directory level is created automatic)
                                                 // -> watch the needed filespace: makes only sense at long term operation
                                                 //    with D_DEBUG_LEVEL 1 - Errors (or 2 -Warnings)
#define WRITE_TO_SYSLOGFILE_INTERVAL_SEC 60      // controls how often the streambuffer of the syslogfile
                                                 // is written to file and how many data can get lost ... (e.g. 60  -> 60 sec are a good value)
#define MAX_SYSLOG_FILE_SIZE_BYTES (100 * 1024)  // there may be problems with serving too big files (>30 kB?) from AsyncWebserver
#define MAX_OLD_SYSLOG_FILES 15

#define S_SERIAL_TO_RADIATOR "Serial2"      // Serial device for connection to radiator device P2/S3100
#define SERIAL_TO_RADIATOR_RX_PIN 16        // ESP32-standard: 16
#define SERIAL_TO_RADIATOR_TX_PIN 17        // ESP32-standard: 17
#define SERIAL_TO_RADIATOR_BAUD 9600        // Baudrate for connection to radiator device P2/S3100
#define T_TIMEOUT_BETWEEN_TRANSFERS_MS 5000 // Maximum time allowed between transfers from P2/S3100 radiator device
                                            // until connection is considered stale.

#define USE_WIFI true
#define WIFI_HOSTNAME "Heizung_Froeling_P2"
#define START_WEBSERVER false // needs activated WiFi (USE_WIFI true)
// #define NUMBER_OF_LOGFILES_TO_COMBINE 92 // download option for webserver: 3 month -> approx 92 day files

// Where to write the values received from the radiator to:
#define OUTPUT_TO_CONSOLE false
#define OUTPUT_TO_MQTT true // needs activated WiFi
#define OUTPUT_TO_FILE true

#if !USE_WIFI
#define START_WEBSERVER false // needs activated WiFi
#define OUTPUT_TO_MQTT false  // needs activated WiFi
#endif

#define FILESYSTEM_TO_USE SD       // SD  (or  LittleFS  (or SPIFFS)) -> errors are NOT HANDLED if filesystem not exists (or SD card not inserted)
#define FILESYSTEM_BASE_PATH "/sd" // "/littlefs" or "/sd" (or "/spiffs") -> MUST CORRESPOND to above filesystem definition
// #define FILESYSTEM_TO_USE LittleFS           // LittleFS or SD (or SPIFFS)
// #define FILESYSTEM_BASE_PATH "/littlefs"     // "/littlefs" or "/sd" (or "/spiffs") -> must correspond to above filesystem definition
#define DATA_DIRECTORY "/P2_Logging"                      // DATA_DIRECTORY: directory for data from radiator -> e.g. "/data" or "" for root dir of used filesystem
                                                          // only one level is created automatically in initFilesystem()
                                                          // ->all deeper directories in path must exist before instantiation of OutputHandler
#define MIN_FREE_KILOBYTES_ON_FILESYSTEM 5000             // if limit is undercut -> oldest logfiles are deleted
#define INTERVALL_FOR_FILESYSTEM_CHECK_SEC (36 * 60 * 60) // execute all 36 hours to check free space on filesystem
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

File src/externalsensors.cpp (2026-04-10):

#include "externalsensors.h"
#include "alarm.h"
#include "debug.h"

#define VENTILATOR_OFF false
#define VENTILATOR_ON true

#define AIR_INPUT_FLAP_CLOSED false
#define AIR_INPUT_FLAP_OPENED true

/*********************
 * STATIC DEFINITIONS
 *********************/
SemaphoreHandle_t radiator::ExternalSensors::semaphoreExternalSensors = NULL;
SemaphoreHandle_t radiator::ExternalSensors::semaphoreAcCurrentSensor = NULL; // Definition für AC-Strom Semaphor
// std::stringstream radiator::ExternalSensors::bufferStringStream;
std::string radiator::ExternalSensors::messageBuf;

bool radiator::ExternalSensors::radiatorIsBurning;

#if WITH_DHT_SENSOR
int radiator::ExternalSensors::dhtGPIO = GPIO_FOR_DHT11;
DHT radiator::ExternalSensors::tempHumidityDHTSensor(GPIO_FOR_DHT11, DHTTYPE);
#endif // WITH_DHT_SENSOR
int16_t radiator::ExternalSensors::lastRoomTemperature = 0;
int16_t radiator::ExternalSensors::lastRoomHumidity = 0;

int radiator::ExternalSensors::ventilatorRelaisGPIO = GPIO_FOR_VENTILATOR_RELAIS;
bool radiator::ExternalSensors::ventilatorRelaisState = VENTILATOR_OFF;

#if WITH_AIR_INPUT_FLAP
int radiator::ExternalSensors::servoForAirInputFlapGPIO = GPIO_FOR_SERVO_FOR_AIR_INPUT_FLAP;
ESP32_Servo radiator::ExternalSensors::servoForAirInputFlap(GPIO_FOR_SERVO_FOR_AIR_INPUT_FLAP);
#endif
bool radiator::ExternalSensors::airInputFlapIsOpen = false;

int radiator::ExternalSensors::leakWaterSensorGPIO = GPIO_FOR_LEAKWATER_SENSOR;
volatile bool radiator::ExternalSensors::leakWaterDetected = false;

int radiator::ExternalSensors::acCurrentSensorGPIO = GPIO_FOR_AC_CURRENT_SENSOR;
Ticker radiator::ExternalSensors::tickerForReadAcCurrentSensor;
volatile int16_t radiator::ExternalSensors::acCurrentAnalogReadAmplitudeMillivolt = 0;

/*********************************************************************
 * @brief 	initialization of external sensors and actors(relais, servo)
 * @param 	GPIOs for the sensors/actors
 *          0 -> disable the specific sensor & functionality
 * @return 	void
 *********************************************************************/
bool radiator::ExternalSensors::initExternalSensors()
{
    semaphoreExternalSensors = xSemaphoreCreateMutex();
    semaphoreAcCurrentSensor = xSemaphoreCreateMutex();
    messageBuf.reserve(2000);

    bool result = true;

#if WITH_DHT_SENSOR
    result &= initTempHumidityDHTSensor();
#endif // WITH_DHT_SENSOR

    result &= initVentilator();

    result &= initAirInputFlap();

    result &= initLeakWaterSensor();

    result &= initAcCurrentSensor();

    TaskHandle_t HandlexTaskExternalSensors;

    // Create RTOS task
    BaseType_t _Result = xTaskCreatePinnedToCore(
        xTaskExternalSensors,        // Task function
        "xTaskExternalSensors",      // String with name of task
        4096,                        // Stack size in bytes
        NULL,                        // Parameter passed as input of the task
        uxTaskPriorityGet(NULL),     // Priority of the task: higher values -> higher priority
                                     // with uxTaskPriorityGet(NULL)-> same priority as current task
        &HandlexTaskExternalSensors, // Task handle (Typ: TaskHandle_t)
        1);                          // Core 0 or 1 (Arduino code by default on Core 1)

    if (_Result != pdPASS)
    {
        throw std::runtime_error("xTaskExternalSensors: Error creating xTask");
    }

    return result;
}

/*********************************************************************
 * @brief 	get all actual sensor values as one string
 * @param 	void
 * @return 	sensor values in format
 *          [Heizungsraum-Temp] = [25°]
 *          [Heizungsraum-Feuchtigkeit] = [70%]"
 *          [Ventilator] = [ON]
 *          [Zuluftklappe] = [ZU]
 *          [Leckwassersensor] = [TROCKEN]
 *          [Stromstaerke] = [3.12A]
 *********************************************************************/
std::string radiator::ExternalSensors::getSensorValues()
{
    static int16_t temp = 0, humidity = 0;

#if WITH_DHT_SENSOR
    if (dhtGPIO != 0) // GPIO defined for functionality enabling?
    {
        if (xSemaphoreTake(semaphoreExternalSensors, pdMS_TO_TICKS(10)) == pdTRUE)
        {
            temp = lastRoomTemperature;
            humidity = lastRoomHumidity;
            xSemaphoreGive(semaphoreExternalSensors);
        }
        else
        {
            // use old/previous values
            //  temp = -999; // Fehlerwert
            //  humidity = -999; // Fehlerwert
            RADIATOR_LOG_ERROR(getMillisAndTime() << "getSensorValues: Fehler beim Nehmen des Semaphores!" << std::endl;)
        }
    }
#endif // WITH_DHT_SENSOR

    return "[Heizungsraum-Temp] = [" +
           std::to_string(temp) + "°] \n" +
           "[Heizungsraum-Feuchtigkeit] = [" + std::to_string(humidity) + "%] \n" +
           "[Ventilator] = " + (std::string)(ventilatorRelaisState ? "[AN]" : "[AUS]") + (std::string) "\n" +
           "[Zuluftklappe] = " + (std::string)(airInputFlapIsOpen ? "[OFFEN]" : "[ZU]") + (std::string) "\n" +
           "[Leckwassersensor] = " + (std::string)(leakWaterDetected ? "[!!!!! ALARM !!!!!]" : "[TROCKEN]") + (std::string) "\n" +
           //  "[Stromstaerke] = [" + std::to_string(getAcCurrentAmpereRMS()) + "A] \n";
           "[Stromstaerke] = [" + getAcCurrentAmpereRMSasString() + "A] \n";
}

/*********************************************************************
 * @brief 	get all actual sensor values as one string in JSON format
 *          - only to add in output.cpp from formatValueDataAsJSON()
 *            -> NOT complete:  {}brackets are missing
 * @param 	void
 * @return 	sensor values in json format WITHOUT {} brackets:
 *          e.g.:   "Heizungsraum-Temp": "25°",
 *                  "Heizungsraum-Feuchtigkeit": "70%",
 *                  "Ventilator": "ON",
 *                  "Zuluftklappe": "ZU",
 *                  "Leckwassersensor": "TROCKEN",
 *                  "Stromstaerke": "3.12A",
 *
 *********************************************************************/
std::string radiator::ExternalSensors::getSensorValuesForJSON()
{
    static int16_t temp = 0, humidity = 0;

#if WITH_DHT_SENSOR
    if (dhtGPIO != 0) // GPIO defined for functionality enabling?
    {
        if (xSemaphoreTake(semaphoreExternalSensors, pdMS_TO_TICKS(10)) == pdTRUE)
        {
            temp = lastRoomTemperature;
            humidity = lastRoomHumidity;
            xSemaphoreGive(semaphoreExternalSensors);
        }
        else
        {
            // use old/previous values
            // temp = -999;     // Fehlerwert
            // humidity = -999; // Fehlerwert
            RADIATOR_LOG_ERROR(getMillisAndTime() << "getSensorValuesForJSON: Fehler beim Nehmen des Semaphores!" << std::endl;)
        }
    }
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

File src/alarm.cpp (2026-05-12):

/******************************************************************************
 * Name:        alarm.cpp
 * @brief       Zentraler Alarm-Manager: einzige Instanz, die auf BUZZER_PIN schreibt.
 *
 * Prioritaeten und Muster: siehe alarm.h
 *
 * Interne Logik:
 *   - activeLevelsMask: jedes Bit repraesentiert ein Level (Bit 1..6)
 *   - Der Buzzer-Task luft endlos und spielt immer das Muster des hoechsten
 *     aktiven Levels.
 *   - raise()/clear() setzen/loeschen das jeweilige Bit und wecken den Task.
 *   - Quit-Taste: setzt quitPressed=true, Task pausiert QUIT_GRACE_PERIOD_S
 *     Sekunden; danach nur Heizungsalarme (Prio>=3) wieder aktiv.
 ******************************************************************************/

#include "alarm.h"
#include "debug.h"
#include "networking.h"

namespace radiator
{
    static portMUX_TYPE alarmMaskMux = portMUX_INITIALIZER_UNLOCKED;

    // ---- statische Membervariablen ----
    volatile uint8_t AlarmManager::activeLevelsMask = 0;
    TaskHandle_t AlarmManager::buzzerTaskHandle = nullptr;
    volatile bool AlarmManager::quitPressed = false;

    // ---- init ----------------------------------------------------------------
    /*********************************************************************
     * @brief 	Initializes BUZZER and QUIT pins, creates the buzzer FreeRTOS task.
     *          Must be called once in setup() before any alarm can be raised.
     * @return 	void
     *********************************************************************/
    void AlarmManager::init()
    {
        pinMode(BUZZER_PIN, OUTPUT);
        digitalWrite(BUZZER_PIN, LOW);
        pinMode(QUIT_BUZZER_BUTTON_PIN, INPUT_PULLUP);

        xTaskCreatePinnedToCore(
            buzzerTask,
            "xTaskAlarmBuzzer",
            3072,
            nullptr,
            uxTaskPriorityGet(nullptr),
            &buzzerTaskHandle,
            1);
    }

    // ---- raise ---------------------------------------------------------------
    /*********************************************************************
     * @brief 	Raise an alarm level.
     *          If this level is new (not yet raised), the optional message is
     *          published via MQTT/log once to avoid message flooding.
     *          The buzzer task is notified to re-evaluate the active pattern.
     * @param 	level    Alarm level to activate
     * @param 	message  Description for MQTT/syslog; nullptr = no message
     * @return 	void
     *********************************************************************/
    void AlarmManager::raise(Level level, const char *message)
    {
        if (level == Level::NONE)
            return;

        const uint8_t bit = (1u << static_cast<uint8_t>(level));
        bool wasNewAlarm = false;

        portENTER_CRITICAL(&alarmMaskMux);
        wasNewAlarm = !(activeLevelsMask & bit);
        activeLevelsMask |= bit;
        portEXIT_CRITICAL(&alarmMaskMux);

        if (message && wasNewAlarm) // publish only on first raise to avoid MQTT flood
        {
            std::string msg = message;
            NetworkHandler::publishToMQTT(msg, MQTT_SUBTOPIC_SYSLOG);
            RADIATOR_LOG_ERROR(getMillisAndTime() << "ALARM raised [" << static_cast<int>(level) << "]: " << msg << std::endl;)
        }

        if (buzzerTaskHandle)
            xTaskNotifyGive(buzzerTaskHandle); // wake buzzer task
    }

    // ---- clear ---------------------------------------------------------------
    /*********************************************************************
     * @brief 	Clear an alarm level.
     *          If this was the highest active alarm, the next lower active alarm
     *          takes over, or the buzzer stops if no alarm remains.
     * @param 	level    Alarm level to deactivate
     * @return 	void
     *********************************************************************/
    void AlarmManager::clear(Level level)
    {
        if (level == Level::NONE)
            return;

        portENTER_CRITICAL(&alarmMaskMux);
        activeLevelsMask &= ~(1u << static_cast<uint8_t>(level));
        portEXIT_CRITICAL(&alarmMaskMux);

        if (buzzerTaskHandle)
            xTaskNotifyGive(buzzerTaskHandle); // buzzer task re-evaluates
    }

    // ---- isActive ------------------------------------------------------------
    /*********************************************************************
     * @brief 	Check if a specific alarm level is currently active.
     * @param 	level    Alarm level to query
     * @return 	true if the given level is currently raised, false otherwise
     *********************************************************************/
    bool AlarmManager::isActive(Level level)
    {
        bool isSet = false;
        portENTER_CRITICAL(&alarmMaskMux);
        isSet = (activeLevelsMask & (1u << static_cast<uint8_t>(level))) != 0;
        portEXIT_CRITICAL(&alarmMaskMux);
        return isSet;
    }

    // ---- activeLevel ---------------------------------------------------------
    /*********************************************************************
     * @brief 	Returns the currently active alarm with the highest priority.
     * @return 	Highest active Level, or Level::NONE if no alarm is active
     *********************************************************************/
    AlarmManager::Level AlarmManager::activeLevel()
    {
        uint8_t maskSnapshot = 0;
        portENTER_CRITICAL(&alarmMaskMux);
        maskSnapshot = activeLevelsMask;
        portEXIT_CRITICAL(&alarmMaskMux);

        for (int i = static_cast<int>(Level::LEAK_WATER); i >= static_cast<int>(Level::ESP_WIFI_LOST); --i)
        {
            if (maskSnapshot & (1u << i))
                return static_cast<Level>(i);
        }
        return Level::NONE;
    }

    // ---- attachQuitInterrupt -------------------------------------------------
    /*********************************************************************
     * @brief 	Attaches a falling-edge interrupt on QUIT_BUZZER_BUTTON_PIN.
     *          The interrupt auto-detaches after the first trigger and sets
     *          quitPressed = true.
     * @return 	void
     *********************************************************************/
    void AlarmManager::attachQuitInterrupt()
    {
        quitPressed = false;
        detachInterrupt(QUIT_BUZZER_BUTTON_PIN);
        attachInterrupt(
            QUIT_BUZZER_BUTTON_PIN,
            []() IRAM_ATTR
            { AlarmManager::quitPressed = true; detachInterrupt(QUIT_BUZZER_BUTTON_PIN); },
            FALLING);
    }
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

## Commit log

2025-07-09 first commit for update from framework arduino 2 to arduino 3
2025-07-10 Refactor analysis module and update configuration
    - Reorganized static definitions in Analysis class for clarity and consistency.
    - Improved the init function to ensure proper initialization and error handling.
    - Enhanced message handling and logging for better debugging.
    - Updated the analysis of heating cycles and fuel levels to reset values correctly at the end of the day.
    - Changed the configuration to deactivate analysis by default.
    - Increased minimum free heap size for MQTT buffer queue to ensure stability.
    - Removed unnecessary SPIFFS include from files.h to streamline dependencies.
    [config.h]
2025-07-10 changed stringstream handling in surveillnace class due to heap problems - now problems with serial
    [config.h]
2025-07-25 fixed SD card problem
    [networking.cpp]
2025-08-13 Big refactor for stability: Main crash reason is timing problem with DHT11 temperatur and humidity sensor -> problem is NOT FIXED, but only functionality deactivated by config.h, because it is not re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
    [config.h, externalsensors.cpp, files.cpp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]
2026-03-21 Fix ESP32 runtime edge cases in WiFi, filesystem and serial handling
    - ensure WiFi password buffer is always null-terminated
    - guard WiFi callback status buffer access with a semaphore
    - avoid front() access on empty logfile list
    - validate day-of-week before console output
    - make serial timeout logic safe across millis() wraparound
    - document remaining shared logging stream concurrency risk
    [files.cpp, networking.cpp]
2026-03-21 mqtt: migrate to bertmelis/espMqttClient@1.7.2 + fix 3 runtime issues
    Replace abandoned marvinroger/AsyncMqttClient@0.9.0 with the actively
    maintained bertmelis/espMqttClient. AsyncTCP/ESPAsyncWebServer unchanged.
    API changes: DisconnectReason enum, setWill uint8_t* payload, reordered
    onMqttMessage params, onMqttSubscribe codes*/len loop.
    Runtime fixes:
    - Exclude USER_OK from auto-reconnect (intentional disconnect)
    - Retry on synchronous connect() failure via ticker
    - Warn on publish() packetId==0; document fire-and-forget queue semantic
    Not yet hardware-tested
    [networking.cpp]
2026-03-21 refactor(alarm): centralize alarm flow and add dedicated service test plan
    [FroelingESP32Housing.3mf]
2026-03-30 docs: update beep signals documentation and add CAD/3D-files
    [FroelingESP32Housing.3mf]
2026-04-04 Update 3D housing files
    [FroelingESP32Housing.3mf]
2026-04-10 fix: harden ESP32 runtime, MQTT retry behavior, and logging stability
    - move WiFi status beeps out of event context into separate task
    - fix non-thread-safe shared logging stream usage
    - improve loop exception handling and restart behavior
    - keep failed MQTT publish entries queued for retry
    - remove temporary hard queue caps, retain heap-based safeguards
    - clean up duplicate runtime log output
    - update setup guide card wording/order
    [alarm.cpp, alarm.h, config.h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]
2026-05-12 fix(alarm): boiler fault buzzer repeat until quit
    [alarm.cpp, alarm.h]
